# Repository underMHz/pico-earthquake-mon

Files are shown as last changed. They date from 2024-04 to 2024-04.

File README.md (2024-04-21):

# pico-earthquake-mon

Raspberry Pi Pico Wを使って「地震情報をリアルタイム」で表示するインフォメーションモニタです。

地震情報は「P2P地震情報」が提供しているWebSocketで取得しています。

[P2P地震情報 - Wikipedia](https://ja.wikipedia.org/wiki/P2P%E5%9C%B0%E9%9C%87%E6%83%85%E5%A0%B1)

地震情報は、震源地・地震の深さ・発生日時・震度・規模の5つがOLED（128×32）に表示されます。

揺れを取得した都道府県は基板上の各LEDに対応しており、揺れた都道府県に対応したLEDが点灯します。

リチウムイオン電池（18650）を使うので、スタンドアロンで使用できます。

----

## 開発環境

・MicroPython(v1.22.2)

・Thonny(v4.0.2)

----

## 動作の様子

動作

実際の動作の様子です。

(上記はテスト用で、受信する地震情報についてはリアルタイムのものではなくダミーとして表示しているものです）

3Dプリンタ（光造形）で作製するスタンドもアップロードしています。

STLファイルは[stand_pico-earthquake-mon.stl](https://github.com/underMHz/pico-earthquake-mon/blob/main/stand_pico-earthquake-mon.stl)にあります。

----

## 部品リスト

|部品名|個数|購入先リンク|注意|
|:--|:--|:--|:--|
|メイン基板|1||BOOTHに出品予定？|
|Raspberry Pi Pico W|1|https://akizukidenshi.com/catalog/g/g117947/||
|タクトスイッチ|1|https://akizukidenshi.com/catalog/g/g103646/|Pi Picoリセット用。色はなんでもよい|
|TP4056 リチウム電池充電モジュール|1|https://amzn.asia/d/iQMhM1q|Amazon等に出回っている汎用充電モジュール|
|XHコネクタ メス|2|https://akizukidenshi.com/catalog/g/g112247/||
|XHコネクタ オス|1-2|https://akizukidenshi.com/catalog/g/g112255/||
|XHコネクタ コンタクト|2|https://akizukidenshi.com/catalog/g/g112264/||
|リチウム電池（18650）|1|リンク省略|生セルでも可|
|リチウム電池（18650）電池ボックス|1|https://akizukidenshi.com/catalog/g/g108407/||
|電線|適宜|https://akizukidenshi.com/catalog/g/g110672/||
|ショットキーバリアダイオードSB240LES|1|https://akizukidenshi.com/catalog/g/g107787/||
|コンデンサ 0.15uF 50V|6|https://akizukidenshi.com/catalog/g/g108145/|バイパスコンデンサ。タンタルコンデンサが好ましい|
|TC74HC595AF|6|https://akizukidenshi.com/catalog/g/g110077/|8bitシフトレジスタ|
|緑色チップLED 1608|49|https://akizukidenshi.com/catalog/g/g111878/||
|チップ抵抗 1/10W 3kΩ|49|https://akizukidenshi.com/catalog/g/g106302/|眩しいため6kΩ程度が望ましい|
|細ピンヘッダ|20*2 4 6|https://akizukidenshi.com/catalog/g/g104398/|Pi Pico固定用とOLED固定用とTP4056モジュール固定用|
|M3×35ボルト|2|リンク省略|基板立て用。長さは35mmでなくてもよい|
|M3ナット|2|リンク省略|基板立て用|
|はんだ|適宜|リンク省略|はんだ用|

----

## ブロック図

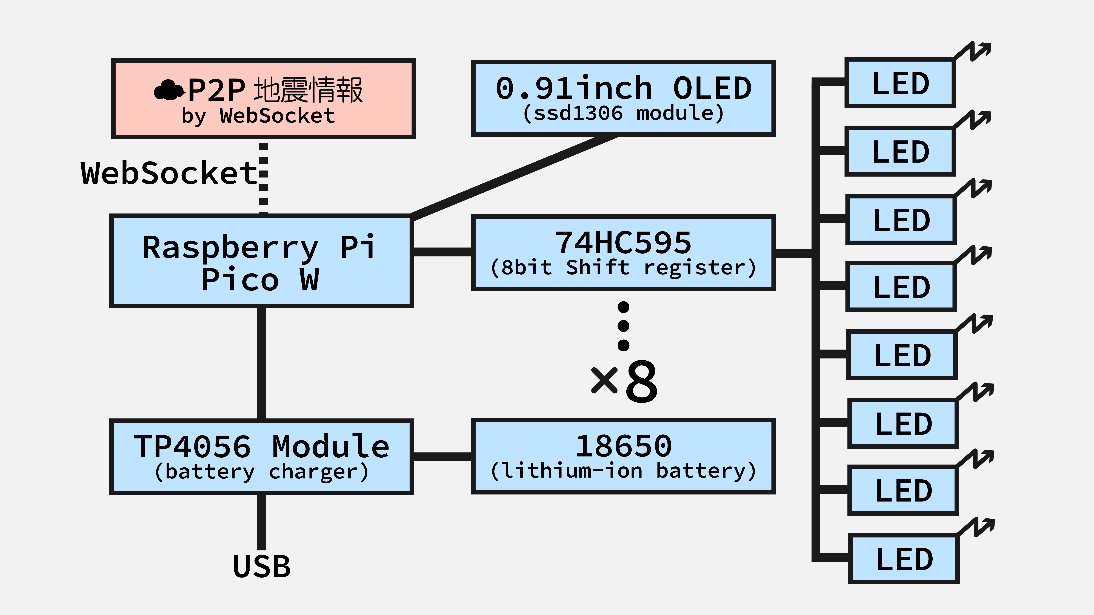
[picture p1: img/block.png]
ブロック図


★Raspberry Pi Pico WをP2P地震情報とWebSocketを使い通信します。

★WebSocketにConnectし、地震情報の受信を待機します。

★受信した情報をパースし、OLEDに地震情報を表示します。

★受信した情報をパースし、揺れた都道府県を取得し、基板上で対応するLEDを点灯させます。

★47都道府県なので、LEDは47個あります。LEDの制御はシフトレジスタ（74HC595）を用います。

★上記47個に加えて、緊急地震速報を示すLEDと機器の接続状況を示すLEDの2個が設定されています。

★スタンドアロンで使用するため、TP4056モジュールを介してRaspberry Pi Pico WのVsysピンへ電源を供給します。

----

## 回路図

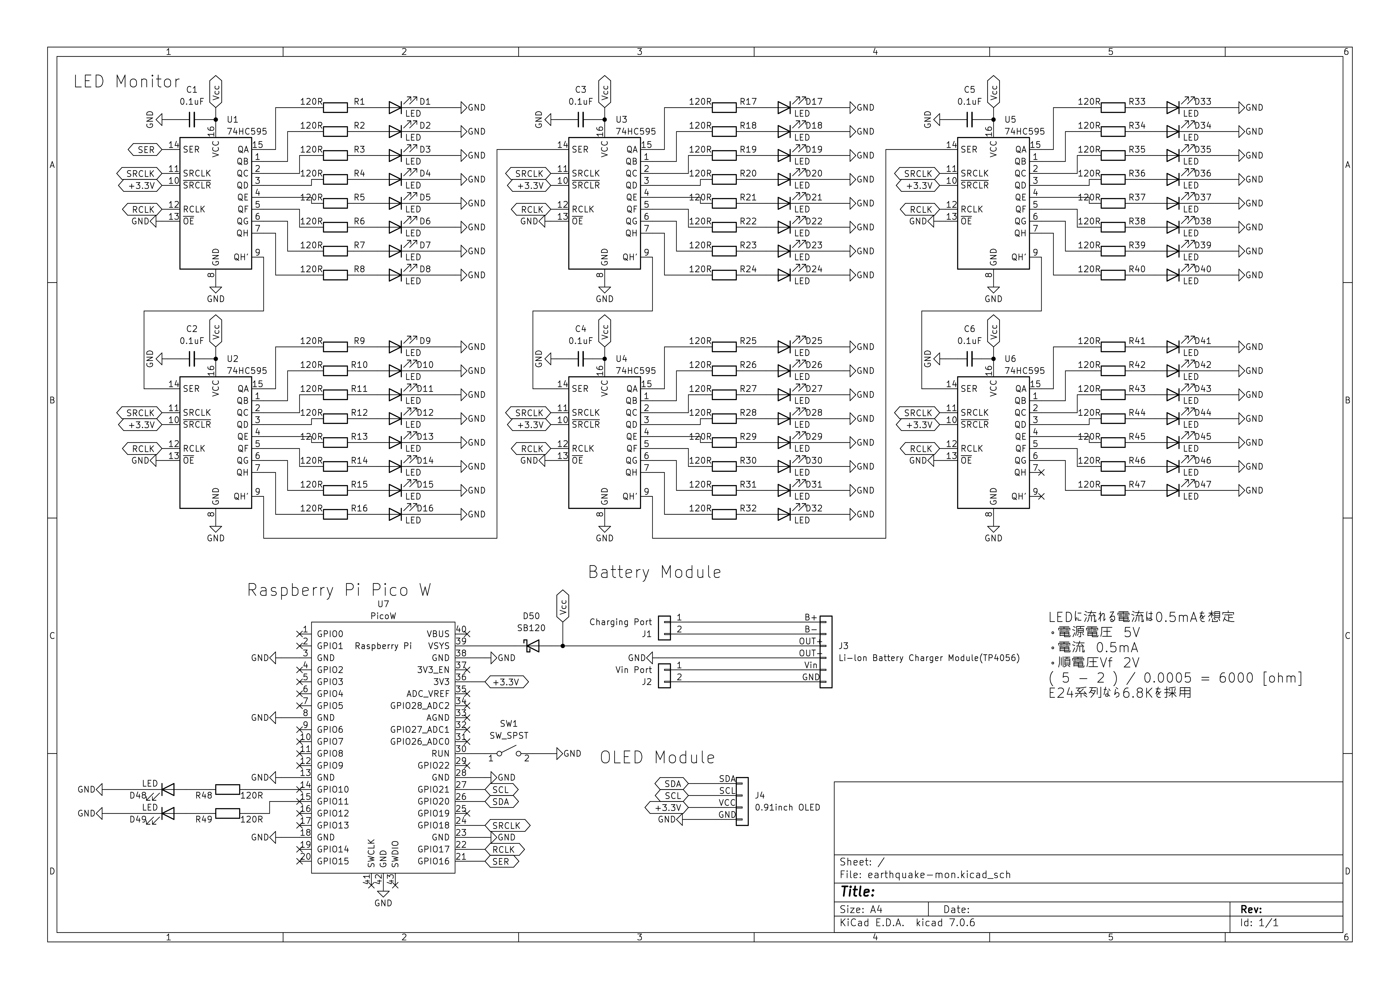
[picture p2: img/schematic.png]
回路図


★シフトレジスタはカスケード接続させています。

★Raspberry Pi Pico WのVsysに電源供給し動作させる場合、ショットキーバリアダイオードが必須です。

★ショットキーバリアダイオードは一般的なダイオード特性に加え、順方向電圧（Vf）が低い点が特徴です。

----

## ガーバーデータ（基板発注のためのデータ）

ガーバーデータは[ここ](https://github.com/underMHz/pico-earthquake-mon/blob/main/gerber_pico-earthquake-mon.zip)からDLできます。

[JLCPCB](https://jlcpcb.com/)での発注を想定しています。

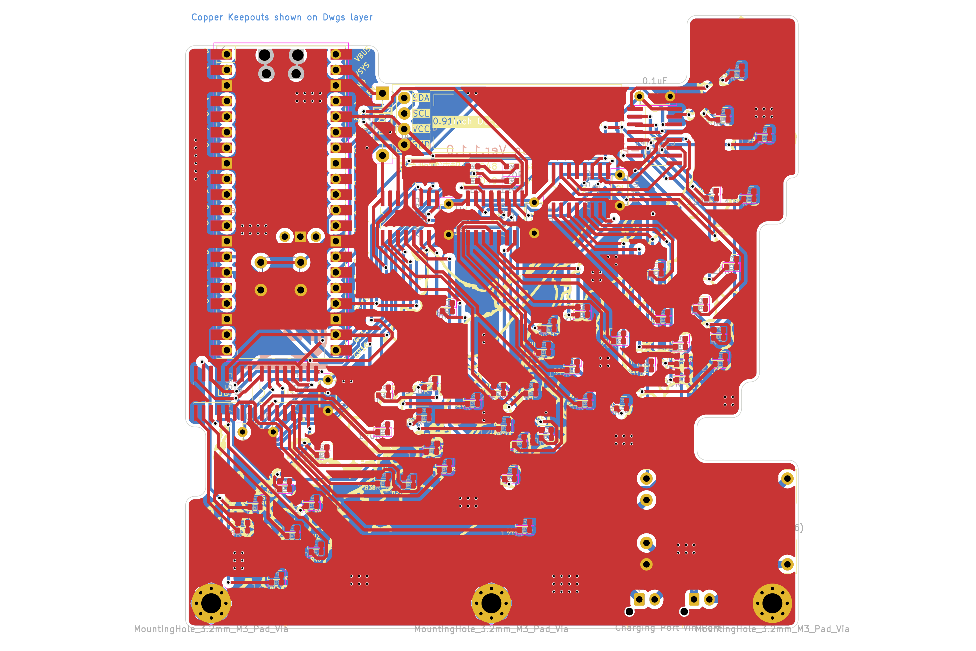
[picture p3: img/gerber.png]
基板


----

## 接続

|PicoW|OLED|74HC595|TP4056 Module|Other|
|:--|:--|:--|:--|:--|
|`VSYS`||`VCC`|`OUT+`||
|`3V3`|`VCC`|`SRCLR`|||
|`GND`|`GND`|`GND` `OE`|`OUT-`||
|`RUN`||||`GND`|
|`GPIO16`||`SER`|||
|`GPIO17`||`RCLK`|||
|`GPIO18`||`SRCLK`|||
|`GPIO20`|`SDA`||||
|`GPIO21`|`SCL`||||
||||`B+`|`Li-Battery+`|
||||`B-`|`Li-Battery-`|
||||`Vin`|`USB+`|
||||`GND`|`USB-`|

・GPIO10に緊急地震速報表示用のLEDを接続

・GPIO11にStatus表示用のLEDを接続

----

## ファイル構成

[pico-earthquake-mon/Raspberry Pi Pico/](https://github.com/underMHz/pico-earthquake-mon/tree/main/Raspberry%20Pi%20Pico)

- **ThonnyからPython Package Index(PyPI)からインストールするライブラリ**

`ssd1306`

- **外部から追加するライブラリ**

`uwebsocketsclient`
https://github.com/underMHz/uwebsockets-client/blob/main/uwebsocketsclient.py

`P2P地震情報（https://www.p2pquake.net/）の証明書(www.p2pquake.net.crt)`
取得方法はディレクトリ構成図の下に記載。

- **使用するフォント**

`misakifont`（美咲フォント）
https://github.com/Tamakichi/pico_MicroPython_misakifont/tree/main/misakifont

❓美咲フォントについて
https://littlelimit.net/misaki.htm

```
Raspberry Pi Pico/
├── lib/
│   ├── ssd1306.py
│   ├── uwebsocketsclient.py
│   └── www.p2pquake.net.crt
├── misakifont/
│   ├── misakifont.py
│   ├── misakifontdata.py
│   ├── tma_jp_utl.py
│   └── __init__.py
├── all_led_test.py
└── main.py
```

- **証明書の取得方法**

Google Chromeでの取得方法を説明します。

URL横のハンバーガーメニューから「この接続は保護されています」をクリックします。

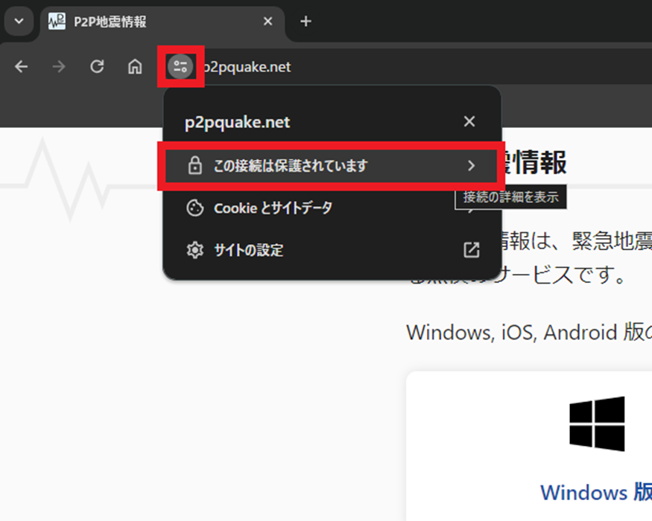
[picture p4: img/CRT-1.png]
証明書の取得方法-1


次に「証明書は有効です」をクリックします。

下画像のようなポップアップが表示されるので、「詳細」タブをクリックします。

そして右下の「エクスポート(X)」をクリックします。

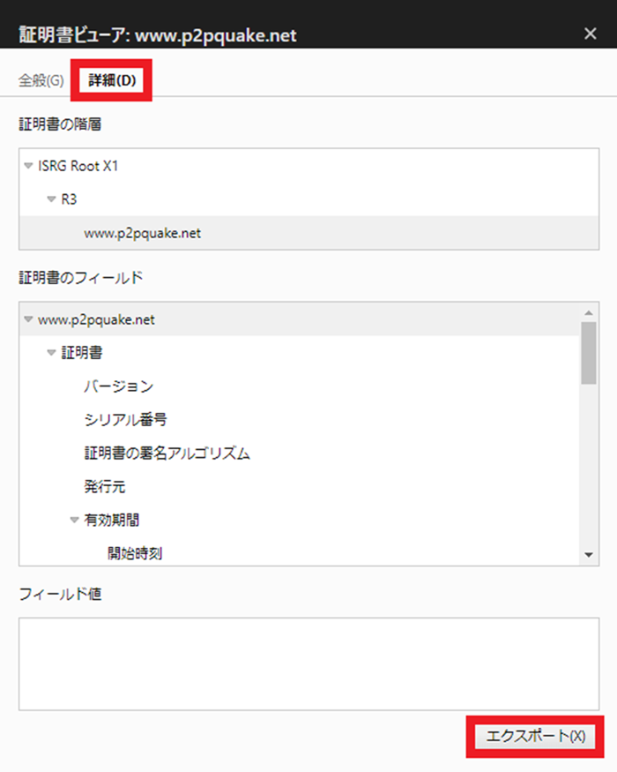
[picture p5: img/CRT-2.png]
証明書の取得方法-2


「Base64 エンコード～証明書チェーン」として保存します。拡張子は「.crt」です。

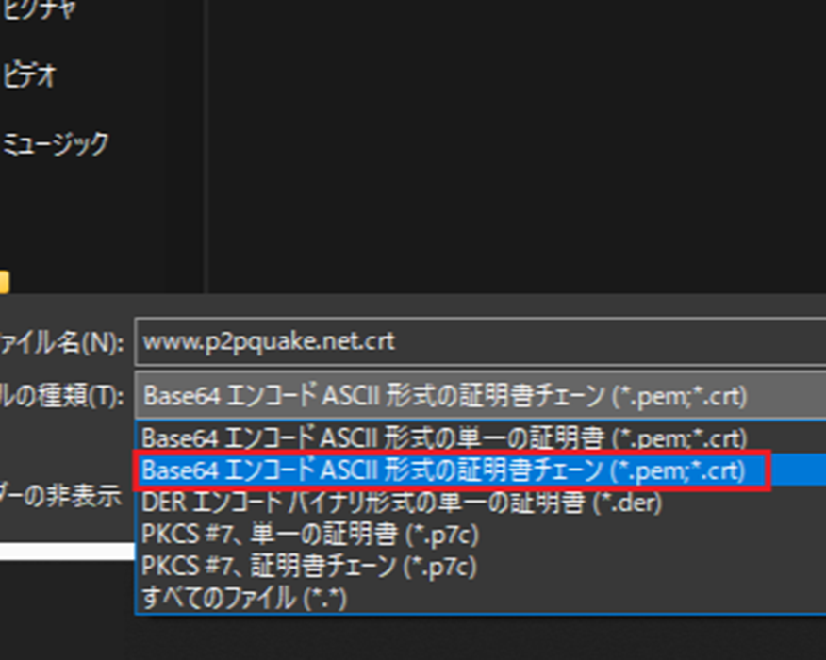
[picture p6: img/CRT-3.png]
証明書の取得方法-3


ダウンロードしたcrtファイルをThonnyを使って「Raspberry Pi Pico/lib」にアップロードします。

----

## コードについて

MicroPythonで開発を行っています。

コードは[ここ](https://github.com/underMHz/pico-earthquake-mon/tree/main/Raspberry%20Pi%20Pico)からDLできます。

main.pyは以下の通り。

```Python
from machine import Pin, I2C
import ssd1306
import framebuf
import time
import sys

import network
import ntptime

from uwebsocketsclient import connect
import ujson as json

from misakifont import MisakiFont

# sandbox (Virtual environment)
#uri = 'wss://api-realtime-sandbox.p2pquake.net:443/v2/ws'

# Production environment
uri = 'wss://api.p2pquake.net:443/v2/ws'

'''
PIN & WiFi Setting
'''
ssid = '***YOUR SSID (2.4GHz)***'
password = '***YOUR PASSWORD***'

alert_led = Pin(10, Pin.OUT)
status_led = Pin(11, Pin.OUT)

# I2C setting (SDA->20, SCL->21)
i2c = I2C(0, sda=Pin(20), scl=Pin(21) )
# Display setting
oled = ssd1306.SSD1306_I2C(128, 32, i2c)

# GP16 -> 14(74HC595)
# GP17 -> 12(74HC595)
# GP18 -> 11(74HC595)
ser_pin = 16
latch_pin = 17
clk_pin = 18

ser = Pin(ser_pin, Pin.OUT)
latch = Pin(latch_pin, Pin.OUT)
clock = Pin(clk_pin, Pin.OUT)

'''
Function to display the point at which the earthquake occurred
'''
fcolor = 1
mf = MisakiFont()

def show_text(text, x, y, fsize, xmax):
    x_origin = x
    for c in text:
        fd = mf.font(ord(c))
        show_bitmap(oled, fd, x, y, fcolor, fsize)
        x += 8 * fsize
        if x >= xmax:
            x = x_origin
            y += 8 * fsize
    oled.show()

def show_bitmap(oled, fd, x, y, color, size):
    for row in range(0, 7):
        for col in range(0, 7):
            if (0x80 >> col) & fd[row]:
                oled.fill_rect(int(x + col * size), int(y + row * size), size, size, color)

'''
functions
'''
def zfill(s, width):
    if len(s) < width:
        return ('0' * (width - len(s))) + s
    else:
        return s
    
def setRegister(ser, clock, val):
    for i in range(0, 8):
        # CLOCK : LOW -> HIGH
        clock.off()
        # Input data in order from the least significant bit
        ser.value(val & (0x01 << i))
        clock.on()
        
def scale_to_value(scale):
    scale_dict = {
        "-1": "?",
        "10": "1",
        "20": "2",
        "30": "3",
        "40": "4",
        "50": "5弱",
        "55": "5強",
        "60": "6弱",
        "65": "6強",
        "70": "7"
    }
    return scale_dict.get(str(scale), "?")

def seismic_intensity(max_scale_value):
    if len(max_scale_value) >= 2:
        max_scale_scale = max_scale_value[1:]
        max_scale_value = max_scale_value[:1]
        show_text(max_scale_scale, 120, 8, 1, 128)
    show_text(max_scale_value, 104, 0, 2, 128)

def seismic_magnitude(magnitude):
    magnitude = str(magnitude)
    show_text('M', 104, 16, 1, 128)
    show_text(magnitude, 104, 24, 1, 128)

def happen_date(date):
    show_text(date, 4, 16, 1, 96)

def happen_time(time):
    show_text(time, 4, 24, 1, 96)

def happen_depth(depth):
    show_text(depth, 0, 8, 1, 96)

def happen_location(location):
    show_text(location, 4, 0, 1, 96)
    
def make_frame():
    oled.fill_rect(0, 0, 2, 8, 1)
    oled.fill_rect(0, 16, 2, 16, 1)
    oled.fill_rect(100, 0, 2, 31, 1)

'''
Prefectures List
'''
def pref_to_led(pref):
    sr1 = {
        "北海道": 0b10000000,
        "青森県": 0b01000000,
        "岩手県": 0b00100000,
        "宮城県": 0b00010000,
        "秋田県": 0b00001000,
        "山形県": 0b00000100,
        "福島県": 0b00000010,
        "茨城県": 0b00000001,
        "青森": 0b01000000,
        "岩手": 0b00100000,
        "宮城": 0b00010000,
        "秋田": 0b00001000,
        "山形": 0b00000100,
        "福島": 0b00000010,
        "茨城": 0b00000001
    }

    sr2 = {
        "栃木県": 0b10000000,
        "群馬県": 0b01000000,
        "埼玉県": 0b00100000,
        "千葉県": 0b00010000,
        "東京都": 0b00001000,
        "神奈川県": 0b00000100,
        "新潟県": 0b00000010,
        "富山県": 0b00000001,
        "栃木": 0b10000000,
        "群馬": 0b01000000,
        "埼玉": 0b00100000,
        "千葉": 0b00010000,
        "東京": 0b00001000,
        "神奈川": 0b00000100,
        "新潟": 0b00000010,
        "富山": 0b00000001
    }

    sr3 = {
        "石川県": 0b10000000,
        "福井県": 0b01000000,
        "山梨県": 0b00100000,
        "長野県": 0b00010000,
        "岐阜県": 0b00001000,
        "静岡県": 0b00000100,
        "愛知県": 0b00000010,
        "三重県": 0b00000001,
        "石川": 0b10000000,
        "福井": 0b01000000,
        "山梨": 0b00100000,
        "長野": 0b00010000,
        "岐阜": 0b00001000,
        "静岡": 0b00000100,
        "愛知": 0b00000010,
        "三重": 0b00000001
    }

    sr4 = {
        "滋賀県": 0b10000000,
        "京都府": 0b01000000,
        "大阪府": 0b00100000,
        "兵庫県": 0b00010000,
        "奈良県": 0b00001000,
        "和歌山県": 0b00000100,
        "鳥取県": 0b00000010,
        "島根県": 0b00000001,
        "滋賀": 0b10000000,
        "京都": 0b01000000,
        "大阪": 0b00100000,
        "兵庫": 0b00010000,
        "奈良": 0b00001000,
        "和歌山": 0b00000100,
        "鳥取": 0b00000010,
        "島根": 0b00000001
    }

    sr5 = {
        "岡山県": 0b10000000,
        "広島県": 0b01000000,
        "山口県": 0b00100000,
        "徳島県": 0b00010000,
        "香川県": 0b00001000,
        "愛媛県": 0b00000100,
        "高知県": 0b00000010,
        "福岡県": 0b00000001,
        "岡山": 0b10000000,
        "広島": 0b01000000,
        "山口": 0b00100000,
        "徳島": 0b00010000,
        "香川": 0b00001000,
        "愛媛": 0b00000100,
        "高知": 0b00000010,
        "福岡": 0b00000001
    }

    sr6 = {
        "佐賀県": 0b10000000,
        "長崎県": 0b01000000,
        "熊本県": 0b00100000,
        "大分県": 0b00010000,
        "宮崎県": 0b00001000,
        "鹿児島県": 0b00000100,
        "沖縄県": 0b00000010,
        "佐賀": 0b10000000,
        "長崎": 0b01000000,
        "熊本": 0b00100000,
        "大分": 0b00010000,
        "宮崎": 0b00001000,
        "鹿児島": 0b00000100,
        "沖縄": 0b00000010
    }
    
    # Make list named srs
    srs = [sr1, sr2, sr3, sr4, sr5, sr6]
    
    # Initial
    initial_binary = 0
    sr1_send = sr2_send = sr3_send = sr4_send = sr5_send = sr6_send = initial_binary

    for idx, sr in enumerate(srs, start=1):
        for prefecture in pref:
            if prefecture in sr:
                bit_value = sr[prefecture]

                if idx == 1:
                    sr1_send = sr1_send + bit_value
                elif idx == 2:
                    sr2_send = sr2_send + bit_value
                elif idx == 3:
                    sr3_send = sr3_send + bit_value
                elif idx == 4:
                    sr4_send = sr4_send + bit_value
                elif idx == 5:
                    sr5_send = sr5_send + bit_value
                elif idx == 6:
                    sr6_send = sr6_send + bit_value

    # LATCH : LOW -> HIGH
    latch.off()
    setRegister(ser, clock, sr6_send)
    setRegister(ser, clock, sr5_send)
    setRegister(ser, clock, sr4_send)
    setRegister(ser, clock, sr3_send)
    setRegister(ser, clock, sr2_send)
    setRegister(ser, clock, sr1_send)
    latch.on()

'''
RESET LED
'''
status_led.off()
alert_led.off()

initial_binary = 0
sr1_send = sr2_send = sr3_send = sr4_send = sr5_send = sr6_send = initial_binary

latch.off()
setRegister(ser, clock, sr6_send)
setRegister(ser, clock, sr5_send)
setRegister(ser, clock, sr4_send)
setRegister(ser, clock, sr3_send)
setRegister(ser, clock, sr2_send)
setRegister(ser, clock, sr1_send)
latch.on()

'''
Display at startup
'''
# Display MicroPython logo
oled.fill_rect(0, 0, 32, 32, 1)
oled.fill_rect(2, 2, 28, 28, 0)
oled.vline(9, 8, 22, 1)
oled.vline(16, 2, 22, 1)
oled.vline(23, 8, 22, 1)
oled.fill_rect(26, 24, 2, 4, 1)
# Display text
oled.text('Run by', 40, 7, 1)
oled.text('MicroPython', 40, 17, 1)
# Show
oled.show()
time.sleep(1.5)

# Hiding the text
oled.fill_rect(32, 0, 128, 32, 0)
oled.show()

'''
Setup to connect to WiFi
'''
wlan = network.WLAN(network.STA_IF)
wlan.active(True)
wlan.connect(ssid, password)

# Loop until connection is established
max_wait = 0
while max_wait <= 20:
    # Hiding the text
    oled.fill_rect(32, 0, 128, 32, 0)
    oled.show()
    if wlan.status() < 0 or wlan.status() >= 3:
        break
    # Display text
    oled.text('Connection', 40, 7, 1)
    oled.text(f'trial:{max_wait}/20', 40, 17, 1)
    oled.show()
    max_wait += 1
    time.sleep(1)
    
wlan_status = wlan.status()
print('Status code:' +str(wlan_status))

# Handle connection error
# Error meanings
# 0  Link Down
# 1  Link Join
# 2  Link NoIp
# 3  Link Up
# -1 Link Fail
# -2 Link NoNet
# -3 Link BadAuth

status = wlan.ifconfig()
#print('ip = ' + status[0])

if wlan_status == 3:
    # Display text
    oled.text('WiFi is', 40, 7, 1)
    oled.text('connected!!', 40, 17, 1)
    # Show
    oled.show()
    time.sleep(1.5)
    # Clear display
    oled.fill(0)
    oled.show()
else:
    # Display text
    oled.text('WiFi is NOT', 40, 7, 1)
    oled.text('connected!!', 40, 17, 1)
    # Show
    oled.show()
    status_led.on()
    sys.exit()

'''
Obtain the time from an NTP server 
(since the time information must be added to the certificate or it will be rejected)
'''
ntptime.settime()

'''
Raspberry Pi Logo
'''
# Raspberry Pi logo as 32x32 bytearray
buffer = bytearray(b"\x00\x00\x00\x00\x00\x00\x00\x00\x00\x00\x00\x00\x00|?\x00\x01\x86@\x80\x01\x01\x80\x80\x01\x11\x88\x80\x01\x05\xa0\x80\x00\x83\xc1\x00\x00C\xe3\x00\x00~\xfc\x00\x00L'\x00\x00\x9c\x11\x00\x00\xbf\xfd\x00\x00\xe1\x87\x00\x01\xc1\x83\x80\x02A\x82@\x02A\x82@\x02\xc1\xc2@\x02\xf6>\xc0\x01\xfc=\x80\x01\x18\x18\x80\x01\x88\x10\x80\x00\x8c!\x00\x00\x87\xf1\x00\x00\x7f\xf6\x00\x008\x1c\x00\x00\x0c \x00\x00\x03\xc0\x00\x00\x00\x00\x00\x00\x00\x00\x00\x00\x00\x00\x00")
fb = framebuf.FrameBuffer(buffer, 32, 32, framebuf.MONO_HLSB)
oled.blit(fb, 49, 0)
oled.show()

'''
functions for getting earthquake information using Websocket
'''
websocket = connect(uri)
 
while True:
    try:
        data = websocket.recv()
        data = json.loads(data)
        
        code = data['code']
            
        # code:556 -> Earthquake Early Warning Alert
        if code == 556:
            # ON alertLED
            alert_led.on()                
            arrival_time = data['earthquake']['arrivalTime']
            # No data -> max_scale = data['earthquake']['maxScale']
            max_scale = '!'
            magnitude = data['earthquake']['hypocenter']['magnitude']
            depth = data['earthquake']['hypocenter']['depth']
            location = data['earthquake']['hypocenter']['name']
            
            pref = list(set(point['pref'] for point in data['areas']))
            
            if magnitude == -1:
                magnitude = '?'
                
            if location == '':
                location = '計測中'

            if depth == -1:
                depth = '?'

            depth = f'（深さ：{depth}㎞）'
            
            arrival_date = arrival_time.split()[0]
            arrival_time = arrival_time.split()[1]
            
            oled.fill(0)
            oled.show()
            
            # Display earthquake information
            seismic_intensity(max_scale_value)
            seismic_magnitude(magnitude)
            happen_depth(depth)
            happen_location(location)
            happen_date(arrival_date)
            happen_time(arrival_time)
            make_frame()
            oled.show()
            
            # Show the prefecture with LED
            pref_to_led(pref)
            
        # code:551 -> Earthquake Information
        elif code == 551:
            # Reset alertLED
            alert_led.off() 
            occurrence_time = data['earthquake']['time']
            max_scale = data['earthquake']['maxScale']
            magnitude = data['earthquake']['hypocenter']['magnitude']
            depth = data['earthquake']['hypocenter']['depth']
            location = data['earthquake']['hypocenter']['name']
            
            pref = list(set(point['pref'] for point in data['points']))
            
            # Converts maximum seismic intensity ID to a numerical value
            max_scale_value = scale_to_value(max_scale)

            if magnitude == -1:
                magnitude = '?'
                
            if location == '':
                location = '計測中'

            if depth == -1:
                depth = '?'

            depth = f'（深さ：{depth}㎞）'
            
            occurrence_date = occurrence_time.split()[0]
            occurrence_time = occurrence_time.split()[1]
            
            oled.fill(0)
            oled.show()
            
            # Display earthquake information
            seismic_intensity(max_scale_value)
            seismic_magnitude(magnitude)
            happen_depth(depth)
            happen_location(location)
            happen_date(occurrence_date)
            happen_time(occurrence_time)
            make_frame()
            oled.show()
            
            # Show the prefecture with LED
            pref_to_led(pref)

        else:
            # Blink
            status_led.on()
            time.sleep(0.5)
            status_led.off()
            time.sleep(0.5)
            status_led.on()
            time.sleep(0.5)
            status_led.off()
            time.sleep(0.5)
            
    except Exception as e:
        status_led.on()
        oled.fill(0)
        oled.show()
        show_text(f'Error:{e}', 0, 0, 1, 128)

```

----

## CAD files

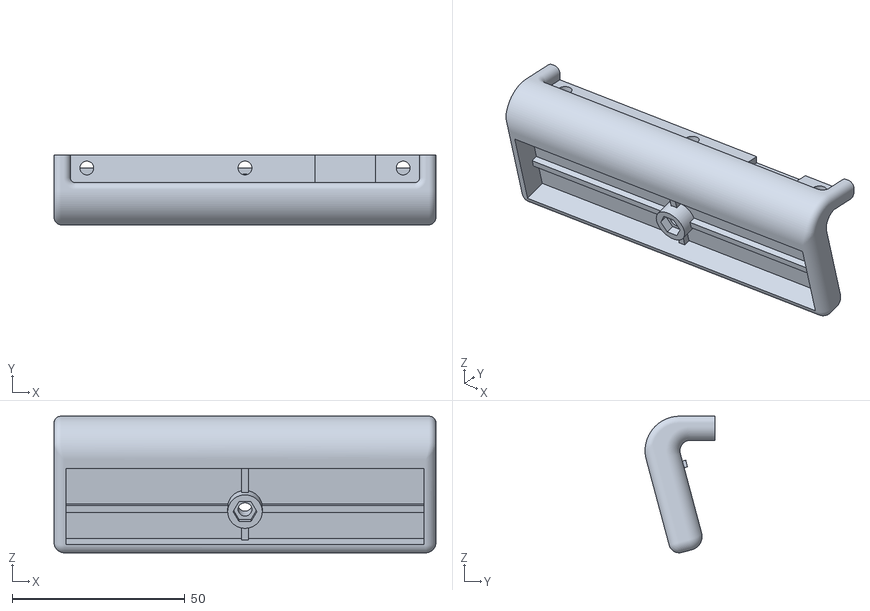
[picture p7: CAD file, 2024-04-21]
stand_pico-earthquake-mon.stl
110.5 x 20.2 x 39.5

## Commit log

2024-04-17 Create all_led_test.py
    全都道府県のLEDを点灯させるテストコード
2024-04-17 全都道府県のLEDを点灯するテストコード
2024-04-17 電源供給すると自動で実行されるファイル
